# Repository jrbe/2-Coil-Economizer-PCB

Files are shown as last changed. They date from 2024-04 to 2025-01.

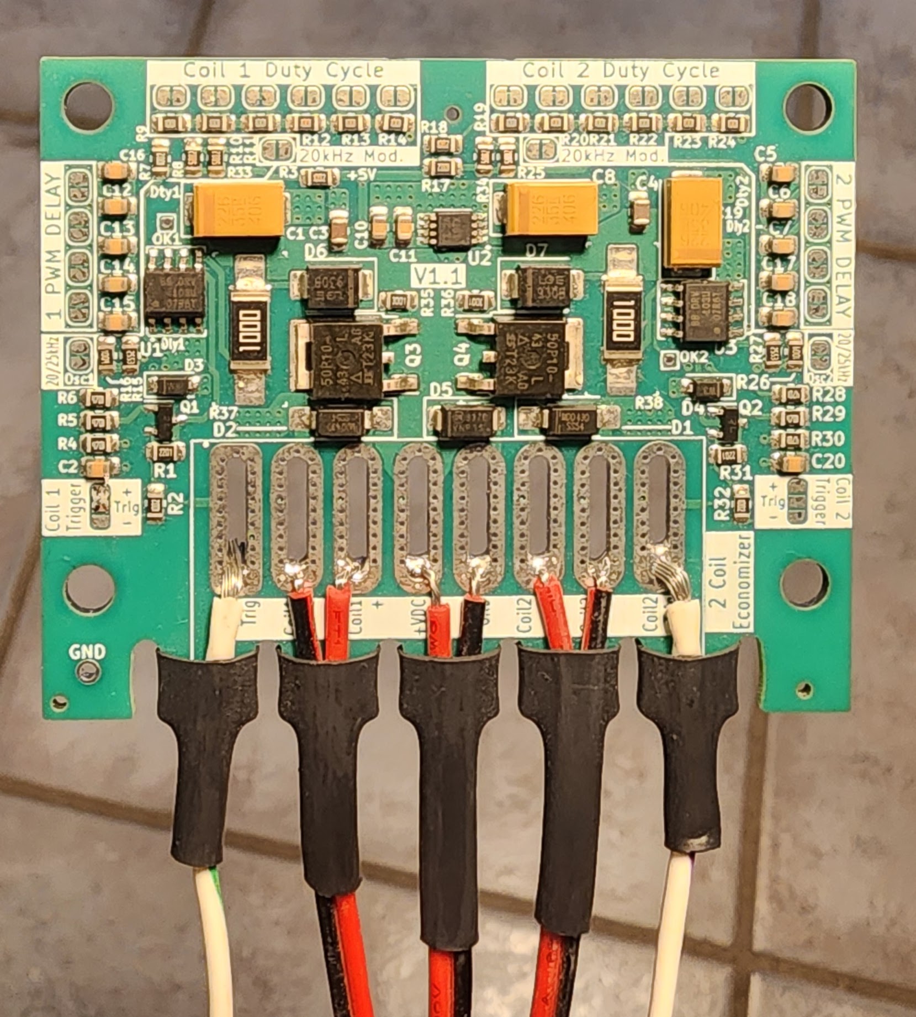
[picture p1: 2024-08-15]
PWM Economizer/PWM Economizer/Images/With Wires.jpg

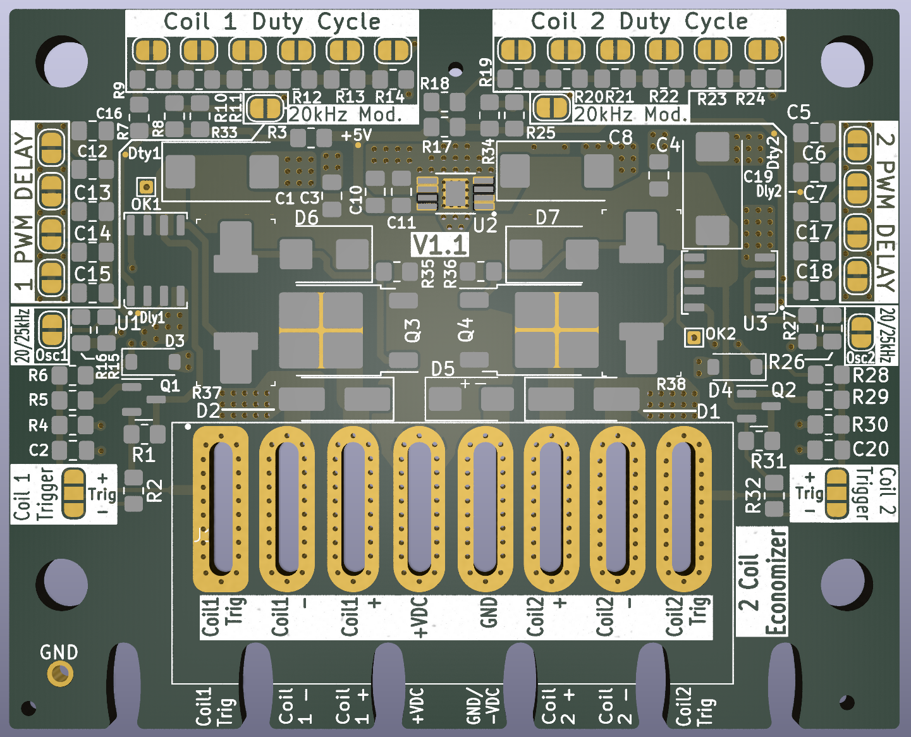
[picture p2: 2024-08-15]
PWM Economizer/PWM Economizer/Images/V1.1 Top Bare.PNG

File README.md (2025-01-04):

**This V1.1 version is not working.  The transistor is flipped on each channel and the DRV103's I got seem to be counterfeit.  Plan is to eventually swap both DRV103's to 556 timers and to a logic ic for flexible input control to reduce cost, eliminate the DRV issues, and simplify the whole project.**

# 2 Coil Economizer PCB
 This 2 Coil DRV103 Economizer PCB is not tested yet. It has at least 1 issue as when its soldered to + triggered the coil output is at 100% with the trigger wire floating. 

It was designed for contactor economizing, for 8-28v, and around 10 amps for each coil. This delivers full power for a short time to pull in the relay or contactor then switches over to a pulse output to conserve power, lower heat, etc. for the coil.
 V1 1 Top Populated

V1 1 Top Bare

The frequency, duty cycle, and delay info is printed on the bottom of the pc board for reference.
V1 1 Bottom

Frequency is set to 25kHz by default.  Its recommended to keep it at 25kHz but can be adjusted from 25kHz down to 20kHz by cutting the 20/25kHz jumpers if required. The 20kHZ mod jumper (follow the silkscreen line to it) must also be soldered to adjust the voltage divider stack to work with the different pwm frequency load requirements of 20kHz for the DRV103 IC.

PWM Duty cycle is set to 21.8% by default, 3 jumpers are shorted on each coil circuit.  This is using voltage to set the duty cycle in the DRV103, a simulation of the circuit is here, https://everycircuit.com/circuit/4973018295828480  These can be cut if necessary.  If more than 21.8% is required more solder jumpers can be soldered.  Which gets cut or soldered doesn't matter as long as its in the silkscreened group. 
Number of jumpers shorted: 0 = 14.3%, 1 = 17%, 2 = 19.75%, 3 = 21.8%, 4 = 23.9%, 5 = 26%, 6 = 28%.  Looking at the top, the left 3 are shorted with a trace across them.

The DRV103 has an adjustable full on time then switches to pwm to hold the coil.  By default all 4 solder jumpers are shorted for a 550ms on time.  These jumpers can be cut to allow less full on time if required. Which gets cut or soldered doesn't matter as long as its in the silkscreened group.
Number of jumpers shorted: 0 = 110ms, 1 = 220ms, 2 = 330ms, 3 = 440ms, 4 = 550ms.

There is a trigger +/- jumper for each coil that needs to be soldered center pad to + or -.  Soldered to + it will turn on the coil with a + signal connected to Coil x trigger.  Soldered to -, it will turn on when the coil trigger is connected to -.  https://everycircuit.com/circuit/4812355044900864 is a simulation of the circuit.

There is an excel file with the calculated values of different DRV103 settings in the references folder.  
Dimensions

The oval slots are oversized for both 5mm and 5.08mm connectors.  This includes Phoenix Contact 1017509, 1751228, 1776260-8, etc. TE 521384-8, Faston tabs, and direct solder.  If direct solder is chosen the "teeth" at the bottom can be used as a strain relief with shrink tubing over them. They are 8mm wide at the bottom.  Small or single wires may require a second layer of shrink tubing.


Testing of the contactors should be done without high voltage connected.  A voltage of 10v or less should be considered for testing to verify the contactors will not accidently open from a low 12v battery. Watching for continuity the coil can be energized and running in pwm mode and hit down on a padded table (simulating a hard bump) with the high voltage terminals up.  There should be no break in continuity and should not open.

Pricey items are the tantalum capacitors that are recommended in the Ti DRV103 datasheet for higher power useage and a few extended JLC components with uncommon resistances.  The DRV103 ICs will likely need to be preordered from JLCPCB or populated later.  

These boards were about $30usd each from JLCPCB at a qty of 5 boards at the time of design.  
Designed in KiCAD 7 
Production files were made using Fabrication Toolkit, https://github.com/bennymeg/Fabrication-Toolkit to correct BOMs, rotations, etc. for JLCPCB.
https://yaqwsx.github.io/jlcparts/#/ was used to find available JLC components.

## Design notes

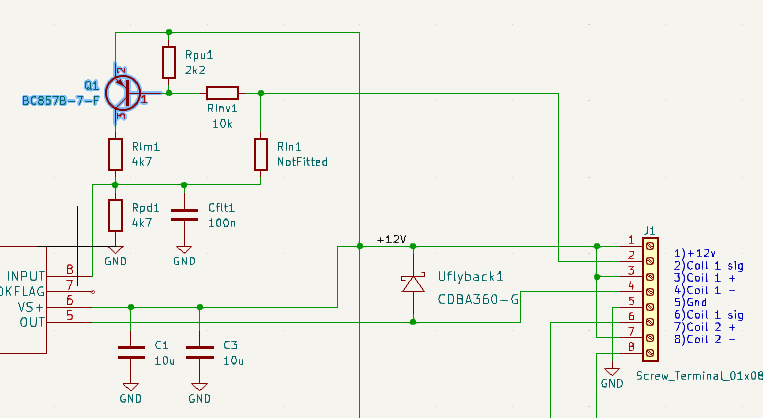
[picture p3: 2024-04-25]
PWM Economizer/PWM Economizer/Images/V0.0/V3.PNG

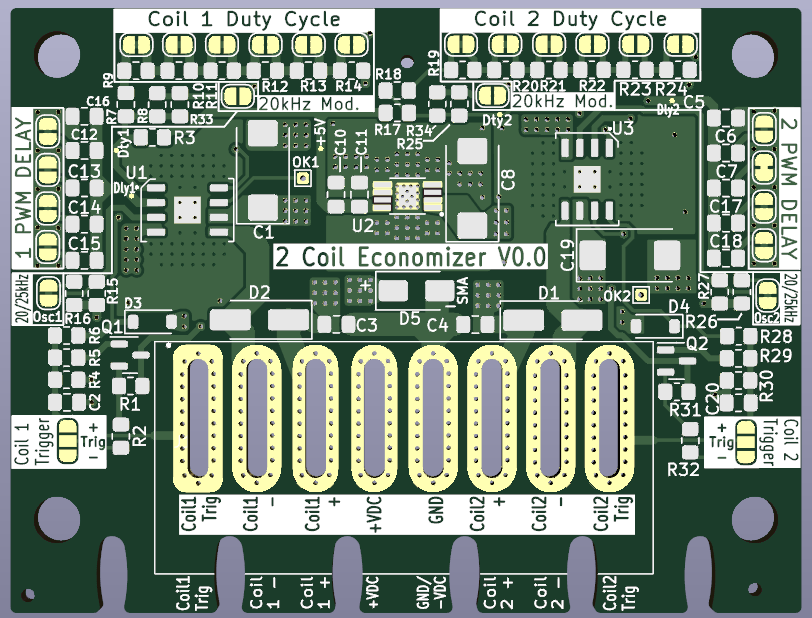
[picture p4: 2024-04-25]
PWM Economizer/PWM Economizer/Images/V0.0/Top Bare.PNG

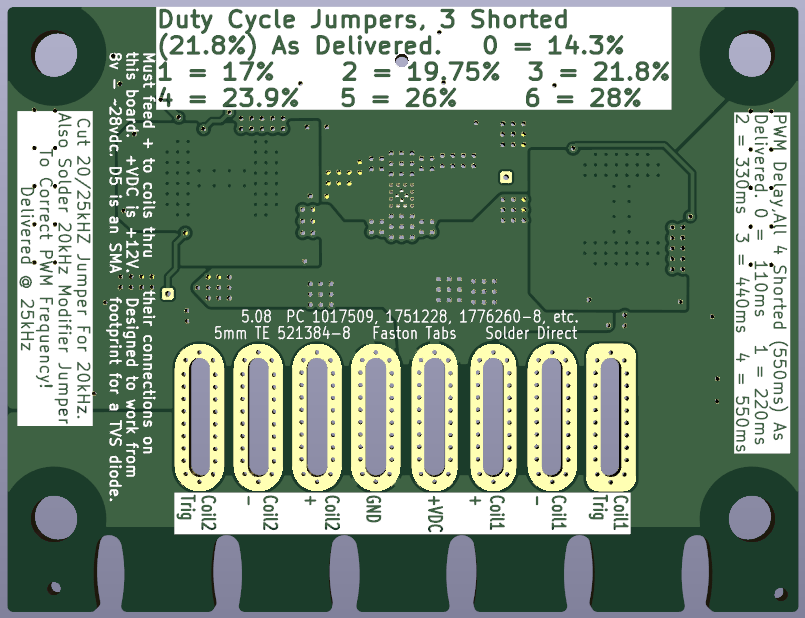
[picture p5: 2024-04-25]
PWM Economizer/PWM Economizer/Images/V0.0/Bottom.PNG

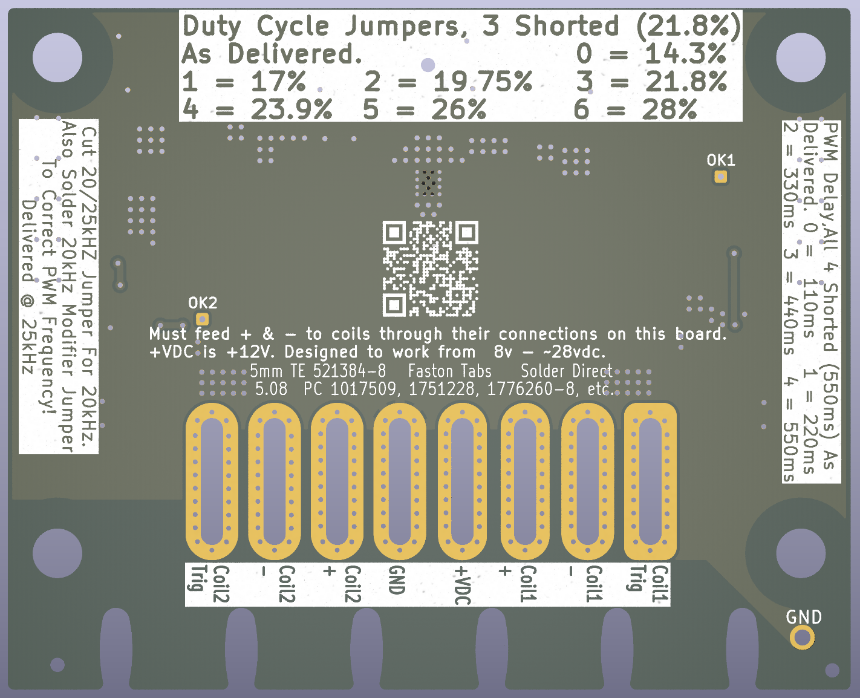
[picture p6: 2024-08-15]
PWM Economizer/PWM Economizer/Images/V1.1 Bottom.PNG

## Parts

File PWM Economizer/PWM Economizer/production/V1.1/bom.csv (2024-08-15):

Designator | Footprint | Quantity | Value | LCSC Part #
C1, C19, C8 | CP_EIA-7343-15_Kemet-W_Pad2.25x2.55mm_HandSolder | 3 | 22uF_LowR | C2798130
C10, C11 | 0805 | 2 | 220nF | C5378
C12, C13, C14, C15, C16, C17, C18, C2, C20, C5, C6, C7 | 0805 | 12 | 100nF | C28233
C3, C4 | 0805 | 2 | 10uF | C440198
D1, D2 | D_SMA_Handsoldering | 2 | D_Schottky | C22452
D3, D4 | D_SOD-123 | 2 | D_Zener | C173413
D5 | D_SMA | 1 | D_Zener | C235776
D6, D7 | D_SMB | 2 | D_16V_Zener | C2940079
H1, H2, H3, H4 | MountingHole_4mm | 4 | MountingHole
JP1, JP26 | SolderJumper-3_P1.3mm_Open_RoundedPad1.0x1.5mm | 2 | Jumper_3_Open
JP10, JP11, JP12, JP13, JP14, JP15, JP16, JP2, JP21, JP22, JP23, JP24, JP25, JP3, JP4, JP9 | SolderJumper-2_P1.3mm_Bridged_RoundedPad1.0x1.5mm | 16 | SJC
JP17, JP18, JP19, JP20, JP5, JP6, JP7, JP8 | SolderJumper-2_P1.3mm_Open_RoundedPad1.0x1.5mm | 8 | SJO
Q1, Q2 | SOT-23 | 2 | PNP | C8326
Q3, Q4 | TO-252-2 | 2 | SUD50P10-43L | C913430
R1, R31 | 0805 | 2 | 2.2K | C17520
R10, R11, R12, R13, R14, R19, R20, R21, R22, R23, R24, R9 | 0805 | 12 | 1k | C17513
R15, R27 | 0805 | 2 | 255k | C3016493
R16, R26 | 0805 | 2 | 1M | C17514
R17, R18, R2, R3, R32, R7 | 0805 | 6 | 10k | C17414
R25, R33, R34, R8 | 0805 | 4 | 100k | C2828840
R28, R29, R30, R4, R5, R6 | 0805 | 6 | 4.7k | C17673
R35, R36 | 0805 | 2 | 3k | C17661
R37, R38 | SMD_Res 3W 12x5.8 & 2512 | 2 | 100R 2W/3W | C309610
TP1, TP2 | TestPoint_THTPad_1.0x1.0mm_Drill0.5mm | 2 | TestPoint
U1, U3 | DRV103 No Heatsink | 2 | DRV103 SO-8 | C1879940
U2 | SOP65P490X110-9N | 1 | TPS7B8250QDGNRQ1 | C424924

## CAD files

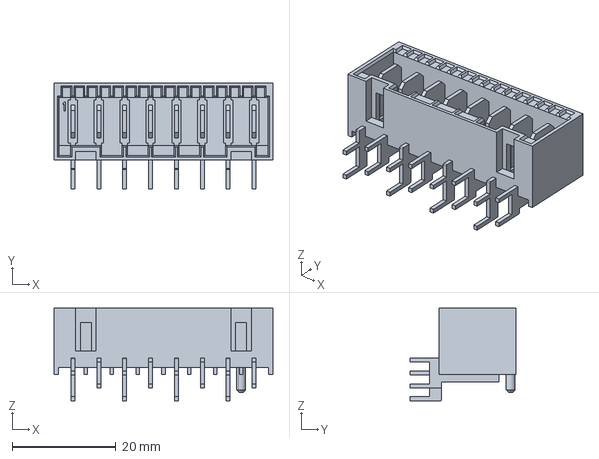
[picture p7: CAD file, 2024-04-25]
PWM Economizer/c-521384-8-d-3d.stp
42.3 x 20.5 x 17.9 mm

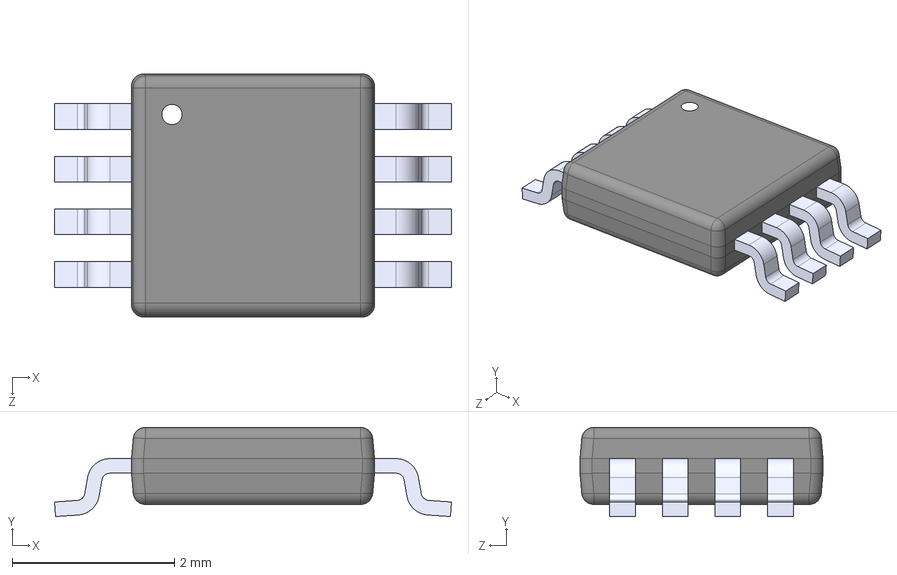
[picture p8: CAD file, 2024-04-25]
PWM Economizer/PWM Economizer/Component Files/TPS7B8250QDGNRQ1/TPS7B8250QDGNRQ1.step
4.90 x 1.10 x 3.00 mm

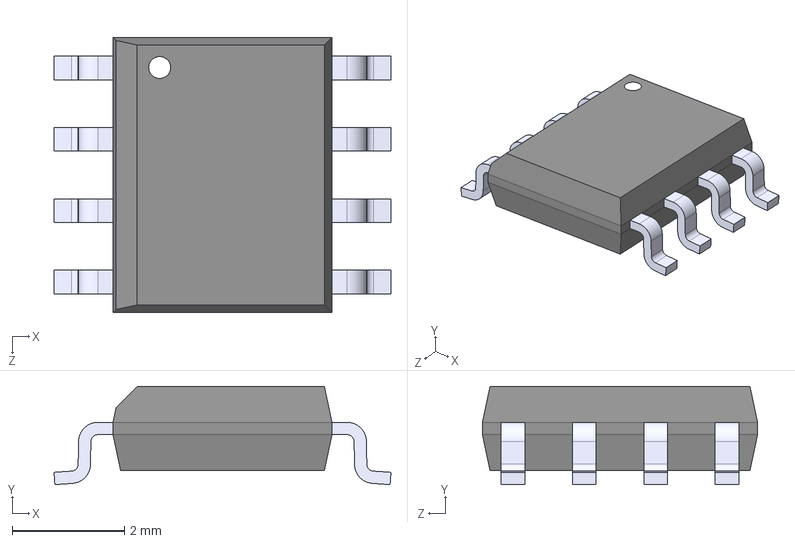
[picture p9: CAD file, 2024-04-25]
PWM Economizer/DRV103U.STEP
6.00 x 1.75 x 4.90 mm

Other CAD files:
PWM Economizer/References/MultiFootprint 1x08.SLDPRT
PWM Economizer/References/MultiFootprint 1x08.DXF

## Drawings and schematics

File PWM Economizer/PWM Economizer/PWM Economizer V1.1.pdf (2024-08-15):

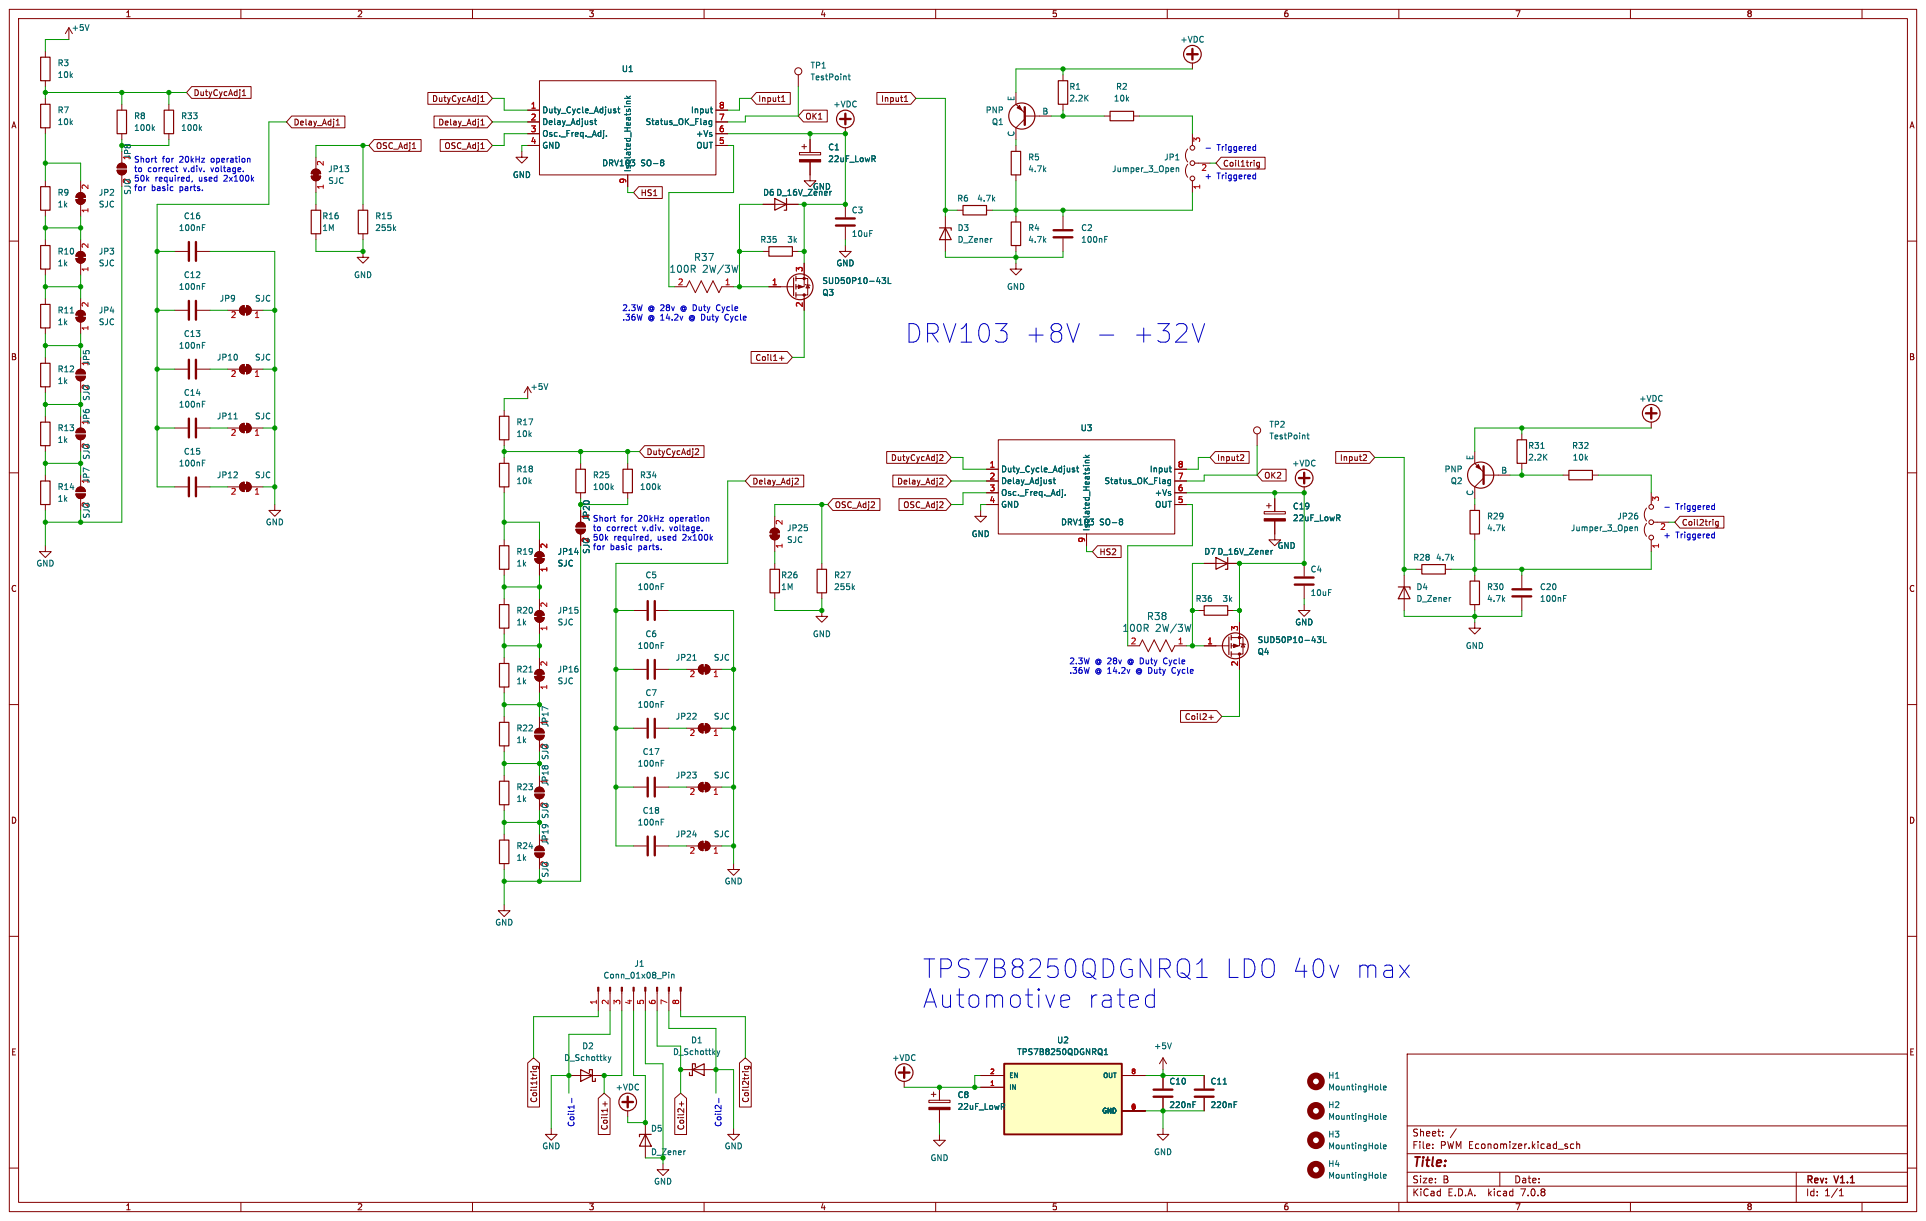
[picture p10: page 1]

1 2 JP20 SJO 1 2 U1 DRV103 SO-8 Duty_Cycle_Adjust 1 Delay_Adjust 2 Osc._Freq._Adj. 3 GND 4 OUT 5 +Vs 6 Status_OK_Flag 7

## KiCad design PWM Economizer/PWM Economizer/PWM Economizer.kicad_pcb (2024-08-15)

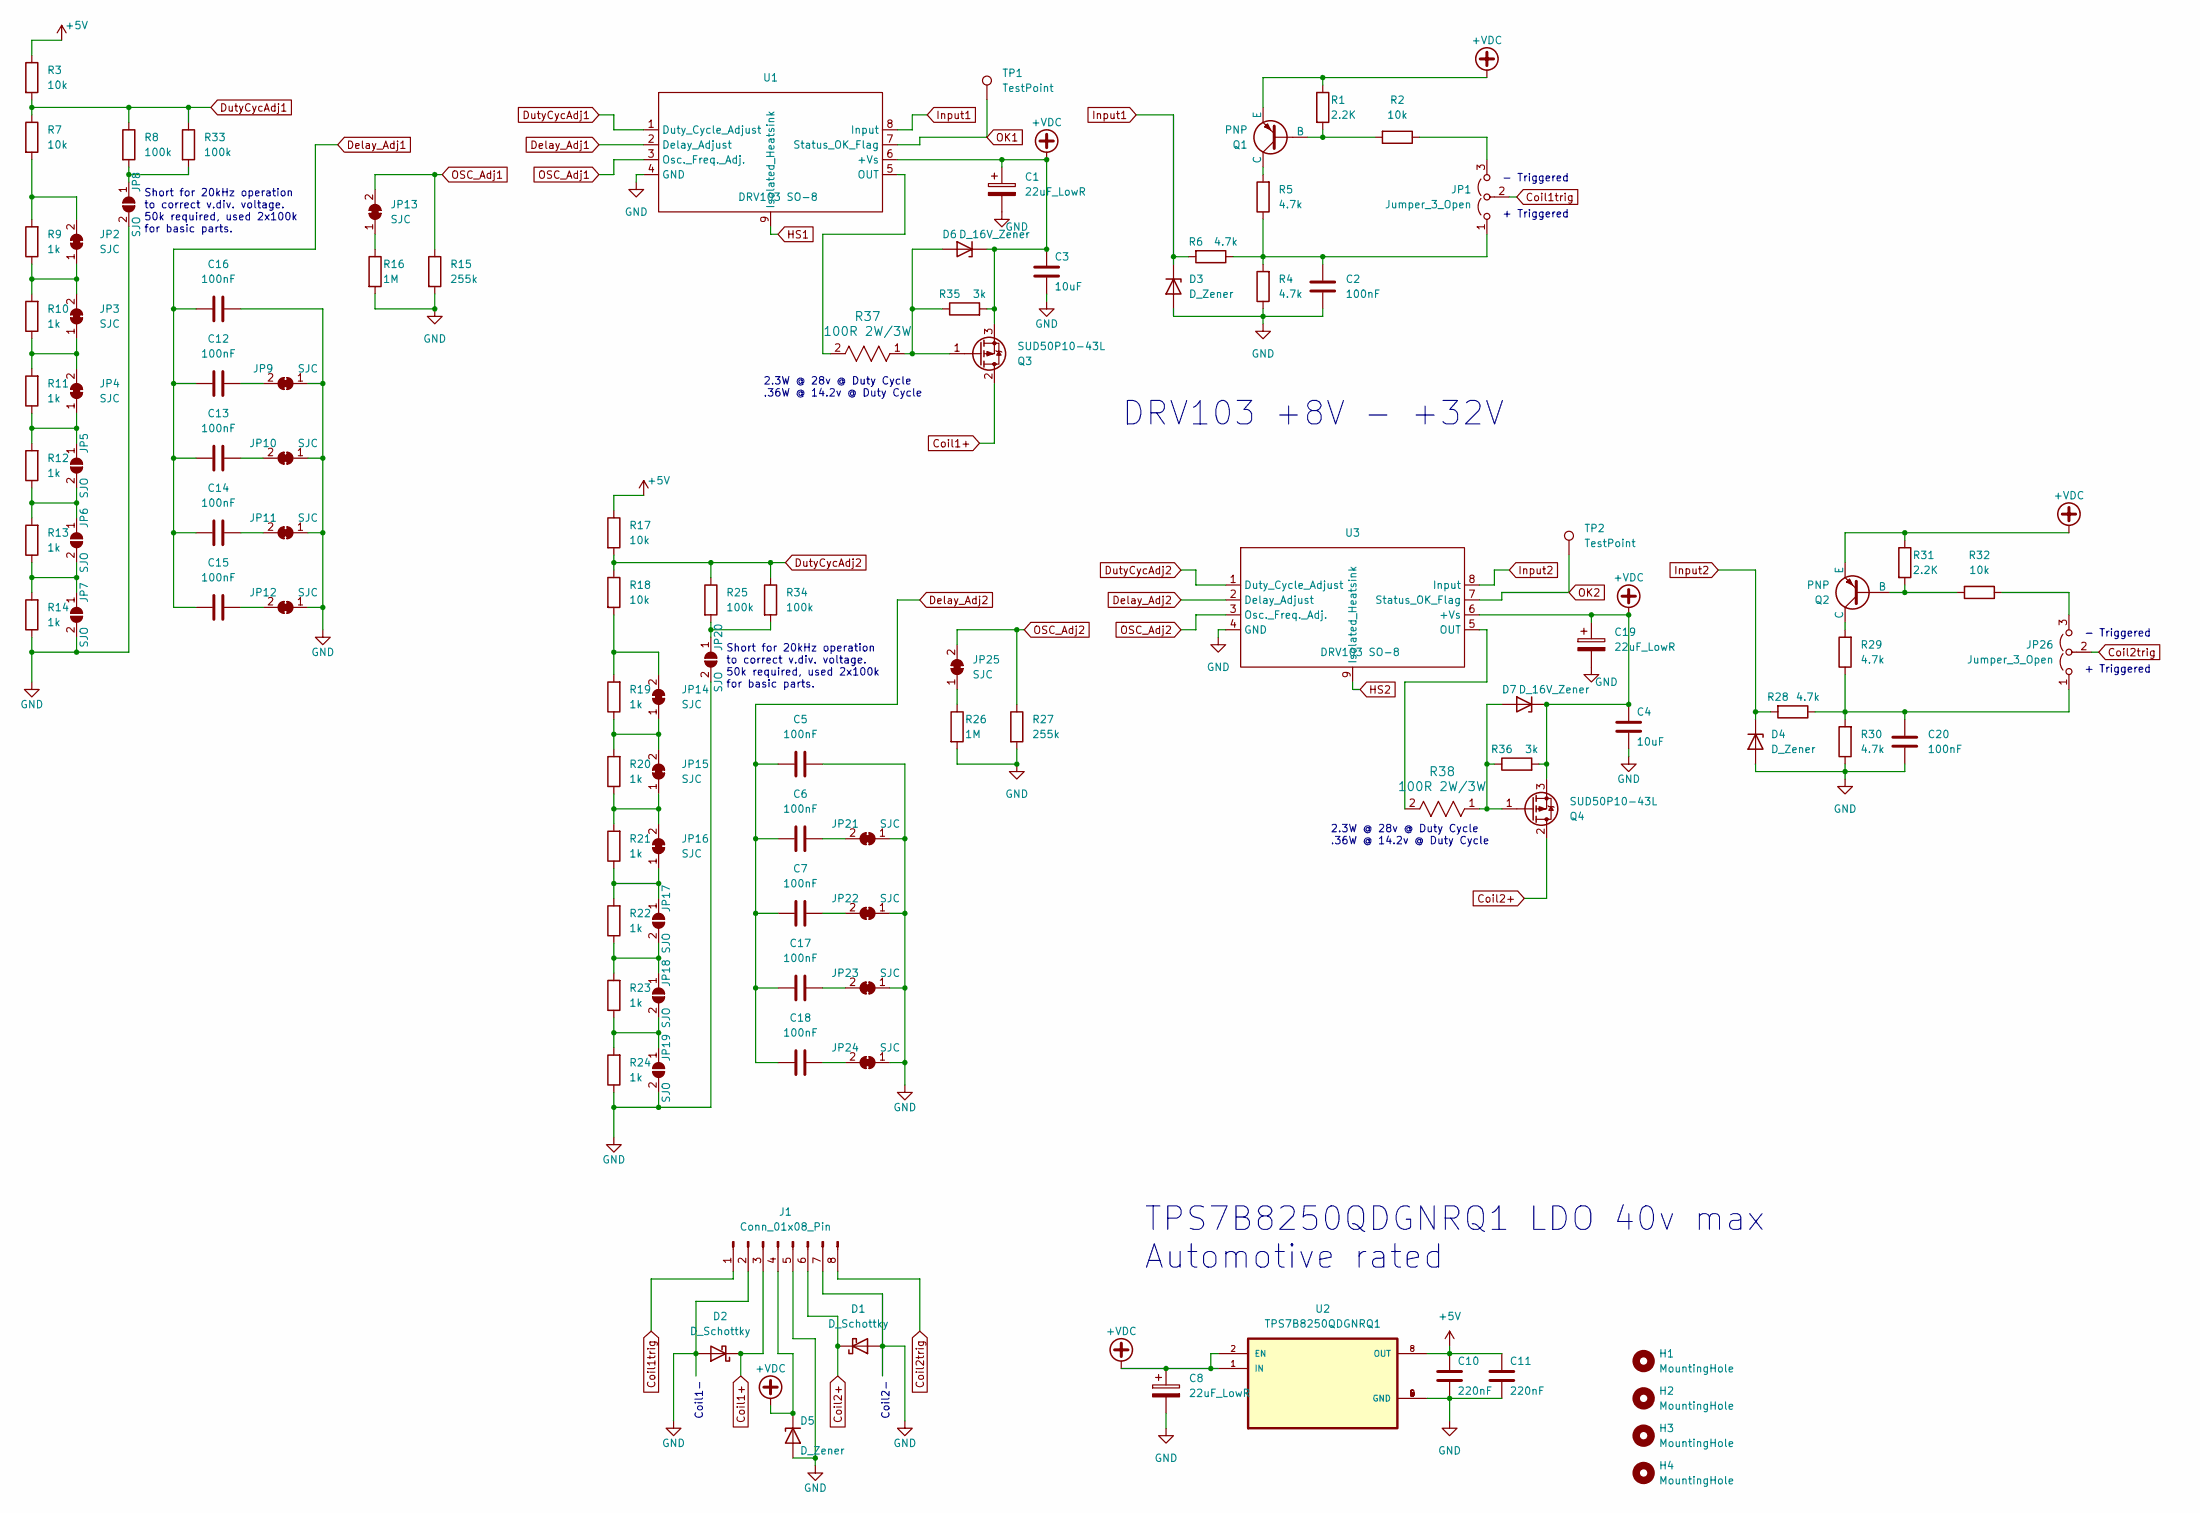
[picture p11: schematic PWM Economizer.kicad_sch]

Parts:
C1, C8, C19: 22uF_LowR; CP_EIA-7343-15_Kemet-W_Pad2.25x2.55mm_HandSolder; LCSC Part C2798130
C2, C5, C6, C7, C12, C13, C14, C15, C16, C17, C18, C20: 100nF; C_0805_2012Metric_Pad1.18x1.45mm_HandSolder; LCSC Part C28233
C3, C4: 10uF; C_0805_2012Metric_Pad1.18x1.45mm_HandSolder; LCSC Part C440198
C10, C11: 220nF; C_0805_2012Metric_Pad1.18x1.45mm_HandSolder; LCSC Part C5378
D1, D2: D_Schottky; D_SMA_Handsoldering; LCSC Part C22452
D3, D4: D_Zener; D_SOD-123; LCSC Part C173413
D5: D_Zener; D_SMA; LCSC Part C235776
D6, D7: D_16V_Zener; D_SMB; LCSC Part C2940079
H1, H2, H3, H4: MountingHole; MountingHole_4mm
J1: Conn_01x08_Pin; Multi-Fit_Faston-SolderedWire-5&5.08mmWireToBoardBlock_1x08
JP1, JP26: Jumper_3_Open; SolderJumper-3_P1.3mm_Open_RoundedPad1.0x1.5mm
JP2, JP3, JP4, JP9, JP10, JP11, JP12, JP13, JP14, JP15, JP16, JP21, JP22, JP23, JP24, JP25: SJC; SolderJumper-2_P1.3mm_Bridged_RoundedPad1.0x1.5mm
JP5, JP6, JP7, JP8, JP17, JP18, JP19, JP20: SJO; SolderJumper-2_P1.3mm_Open_RoundedPad1.0x1.5mm
Q1, Q2: PNP; SOT-23; LCSC Part C8326
Q3, Q4: SUD50P10-43L; TO-252-2; LCSC Part C913430
R1, R31: 2.2K; R_0805_2012Metric_Pad1.20x1.40mm_HandSolder; LCSC Part C17520
R2, R3, R7, R17, R18, R32: 10k; R_0805_2012Metric_Pad1.20x1.40mm_HandSolder; LCSC Part C17414
R4, R5, R6, R28, R29, R30: 4.7k; R_0805_2012Metric_Pad1.20x1.40mm_HandSolder; LCSC Part C17673
R8, R25, R33, R34: 100k; R_0805_2012Metric_Pad1.20x1.40mm_HandSolder; Manufacturer Part No. ARG05DTC5002; LCSC Part C2828840
R9, R10, R11, R12, R13, R14, R19, R20, R21, R22, R23, R24: 1k; R_0805_2012Metric_Pad1.20x1.40mm_HandSolder; Manufacturer Part No. RC0805JR-071M5L; LCSC Part C17513
R15, R27: 255k; R_0805_2012Metric_Pad1.20x1.40mm_HandSolder; Manufacturer Part No. SCR0805F255K; LCSC Part C3016493
R16, R26: 1M; R_0805_2012Metric_Pad1.20x1.40mm_HandSolder; LCSC Part C17514
R35, R36: 3k; R_0805_2012Metric_Pad1.20x1.40mm_HandSolder; Manufacturer Part No. 0805W8F3001T5E; LCSC Part C17661
R37, R38: 100R 2W/3W; SMD_Res 3W 12x5.8 & 2512; LCSC Part C309610
TP1, TP2: TestPoint; TestPoint_THTPad_1.0x1.0mm_Drill0.5mm
U1, U3: DRV103 SO-8; DRV103 No Heatsink; Manufacturer Part No. DRV103U; LCSC Part C1879940
U2: TPS7B8250QDGNRQ1; SOP65P490X110-9N; Manufacturer Part No. TPS7B8250QDGNRQ1; LCSC Part C424924

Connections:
+5V: C10.1, C11.1, R3.1, R17.1, U2.8 (OUT)
+VDC: C1.1, C3.1, C4.1, C8.1, C19.1, D5.1 (K), D6.1 (K), D7.1 (K), J1.4, Q1.3 (E), Q2.3 (E), Q3.3 (S), Q4.3 (S), R1.1, R31.1, R35.2, R36.2, U1.6 (+Vs), U2.1 (IN), U2.2 (EN), U3.6 (+Vs)
Coil1+: D2.1 (K), J1.3, Q3.2 (D)
Coil1trig: J1.1, JP1.2 (C)
Coil2+: D1.1 (K), J1.6, Q4.2 (D)
Coil2trig: J1.8, JP26.2 (C)
Delay_Adj1: C12.1, C13.1, C14.1, C15.1, C16.1, U1.2 (Delay_Adjust)
Delay_Adj2: C5.1, C6.1, C7.1, C17.1, C18.1, U3.2 (Delay_Adjust)
DutyCycAdj1: R3.2, R7.1, R8.1, R33.1, U1.1 (Duty_Cycle_Adjust)
DutyCycAdj2: R17.2, R18.1, R25.1, R34.1, U3.1 (Duty_Cycle_Adjust)
GND: C1.2, C2.2, C3.2, C4.2, C5.2, C8.2, C10.2, C11.2, C16.2, C19.2, C20.2, D1.2 (A), D2.2 (A), D3.2 (A), D4.2 (A), D5.2 (A), J1.2, J1.5, J1.7, JP7.2 (B), JP8.2 (B), JP9.1 (A), JP10.1 (A), JP11.1 (A), JP12.1 (A), JP19.2 (B), JP20.2 (B), JP21.1 (A), JP22.1 (A), JP23.1 (A), JP24.1 (A), R4.1, R14.1, R15.2, R16.2, R24.1, R26.2, R27.2, R30.1, U1.4 (GND), U2.4 (GND), U2.5 (GND), U2.6 (GND), U2.9 (GND), U3.4 (GND)
Input1: D3.1 (K), R6.2, U1.8 (Input)
Input2: D4.1 (K), R28.2, U3.8 (Input)
unnamed: D6.2 (A), Q3.1 (G), R35.1, R37.1
unnamed: D7.2 (A), Q4.1 (G), R36.1, R38.1
unnamed: C2.1, JP1.1 (A), R4.2, R5.1, R6.1
unnamed: JP1.3 (B), R2.1
unnamed: JP2.1 (A), JP3.2 (B), R9.1, R10.2
unnamed: JP2.2 (B), R7.2, R9.2
unnamed: JP3.1 (A), JP4.2 (B), R10.1, R11.2
unnamed: JP4.1 (A), JP5.1 (A), R11.1, R12.2
unnamed: JP5.2 (B), JP6.1 (A), R12.1, R13.2
unnamed: JP6.2 (B), JP7.1 (A), R13.1, R14.2
unnamed: JP8.1 (A), R8.2, R33.2
unnamed: C12.2, JP9.2 (B)
unnamed: C13.2, JP10.2 (B)
unnamed: C14.2, JP11.2 (B)
unnamed: C15.2, JP12.2 (B)
unnamed: JP13.1 (A), R16.1
unnamed: JP14.1 (A), JP15.2 (B), R19.1, R20.2
unnamed: JP14.2 (B), R18.2, R19.2
unnamed: JP15.1 (A), JP16.2 (B), R20.1, R21.2
unnamed: JP16.1 (A), JP17.1 (A), R21.1, R22.2
unnamed: JP17.2 (B), JP18.1 (A), R22.1, R23.2
unnamed: JP18.2 (B), JP19.1 (A), R23.1, R24.2
unnamed: JP20.1 (A), R25.2, R34.2
unnamed: C6.2, JP21.2 (B)
unnamed: C7.2, JP22.2 (B)
unnamed: C17.2, JP23.2 (B)
unnamed: C18.2, JP24.2 (B)
unnamed: JP25.1 (A), R26.1
unnamed: C20.1, JP26.1 (A), R28.1, R29.1, R30.2
unnamed: JP26.3 (B), R32.1
unnamed: Q1.2 (B), R1.2, R2.2
unnamed: Q1.1 (C), R5.2
unnamed: Q2.2 (B), R31.2, R32.2
unnamed: Q2.1 (C), R29.2
unnamed: R37.2, U1.5 (OUT)
unnamed: R38.2, U3.5 (OUT)
OK1: TP1.1, U1.7 (Status_OK_Flag)
OK2: TP2.1, U3.7 (Status_OK_Flag)
OSC_Adj1: JP13.2 (B), R15.1, U1.3 (Osc._Freq._Adj.)
OSC_Adj2: JP25.2 (B), R27.1, U3.3 (Osc._Freq._Adj.)

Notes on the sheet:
Short for 20kHz operation to correct v.div. voltage. 50k required, used 2x100k for basic parts.
Coil2-
2.3W @ 28v @ Duty Cycle .36W @ 14.2v @ Duty Cycle
- Triggered + Triggered
Coil1-
DRV103 +8V - +32V
TPS7B8250QDGNRQ1 LDO 40v max Automotive rated

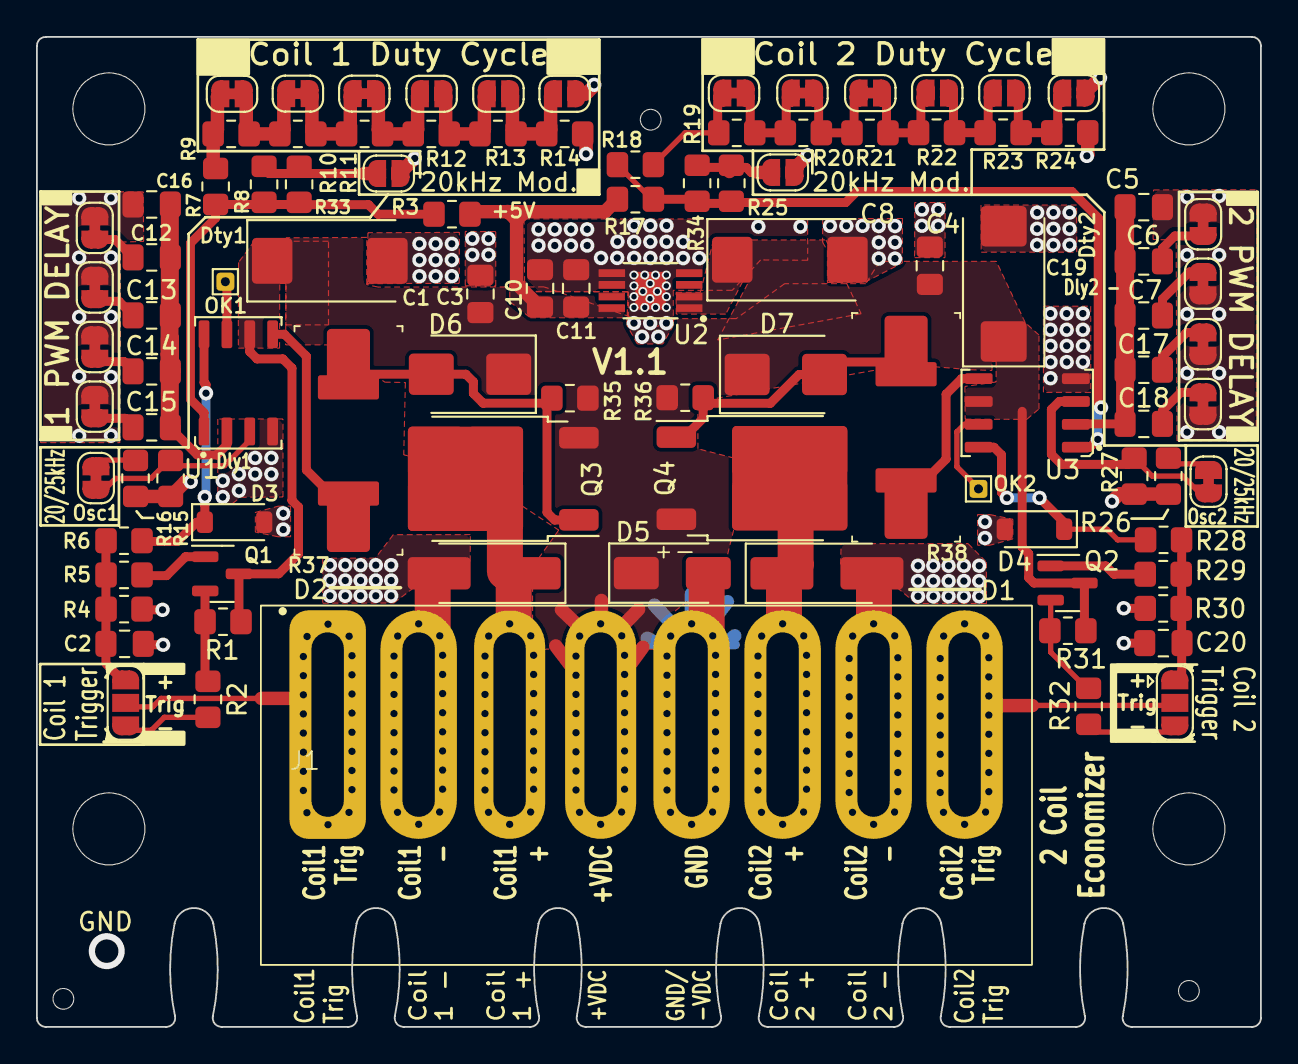
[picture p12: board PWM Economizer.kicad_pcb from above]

Board: 2 copper layers, 68.0 x 55.0 mm, 104 parts (0 on the bottom side), 53 nets.

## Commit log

2024-04-25 Uploading
    Uploading
    [DRV103 preliminary resistor settings V1.xlsx, DRV103U.STEP, MultiFootprint 1x08.DXF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]
2024-04-25 Create PWM Economizer V0.0.step
2024-08-15 V1.1 Untested
    V1.1 Untested
    [PWM Economizer.kicad_pcb, PWM Economizer.kicad_sch, bom.csv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]
